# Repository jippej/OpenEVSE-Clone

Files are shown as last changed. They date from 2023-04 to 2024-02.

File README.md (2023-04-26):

# OpenEVSE-Clone

This is an hardware design which is based on OpenEVSE, compatible with the OpenEVSE firmware, and suited to my needs.
Key changes in respect to the original OpenEVSE boards (version 5.5):
- Removed DC relais control (I use a AC controlled relais)
- GFCI detection removed (I use an external ELCB)
- Removed AC/DC converter (I use an external DIN rail mounted 12VDC supply)
- form factor adjusted to be fitted in a standard DIN rail housing
- Added H-Bridge driver for "cable lock" mechanism
- Added mounting for ESP32 Gateway

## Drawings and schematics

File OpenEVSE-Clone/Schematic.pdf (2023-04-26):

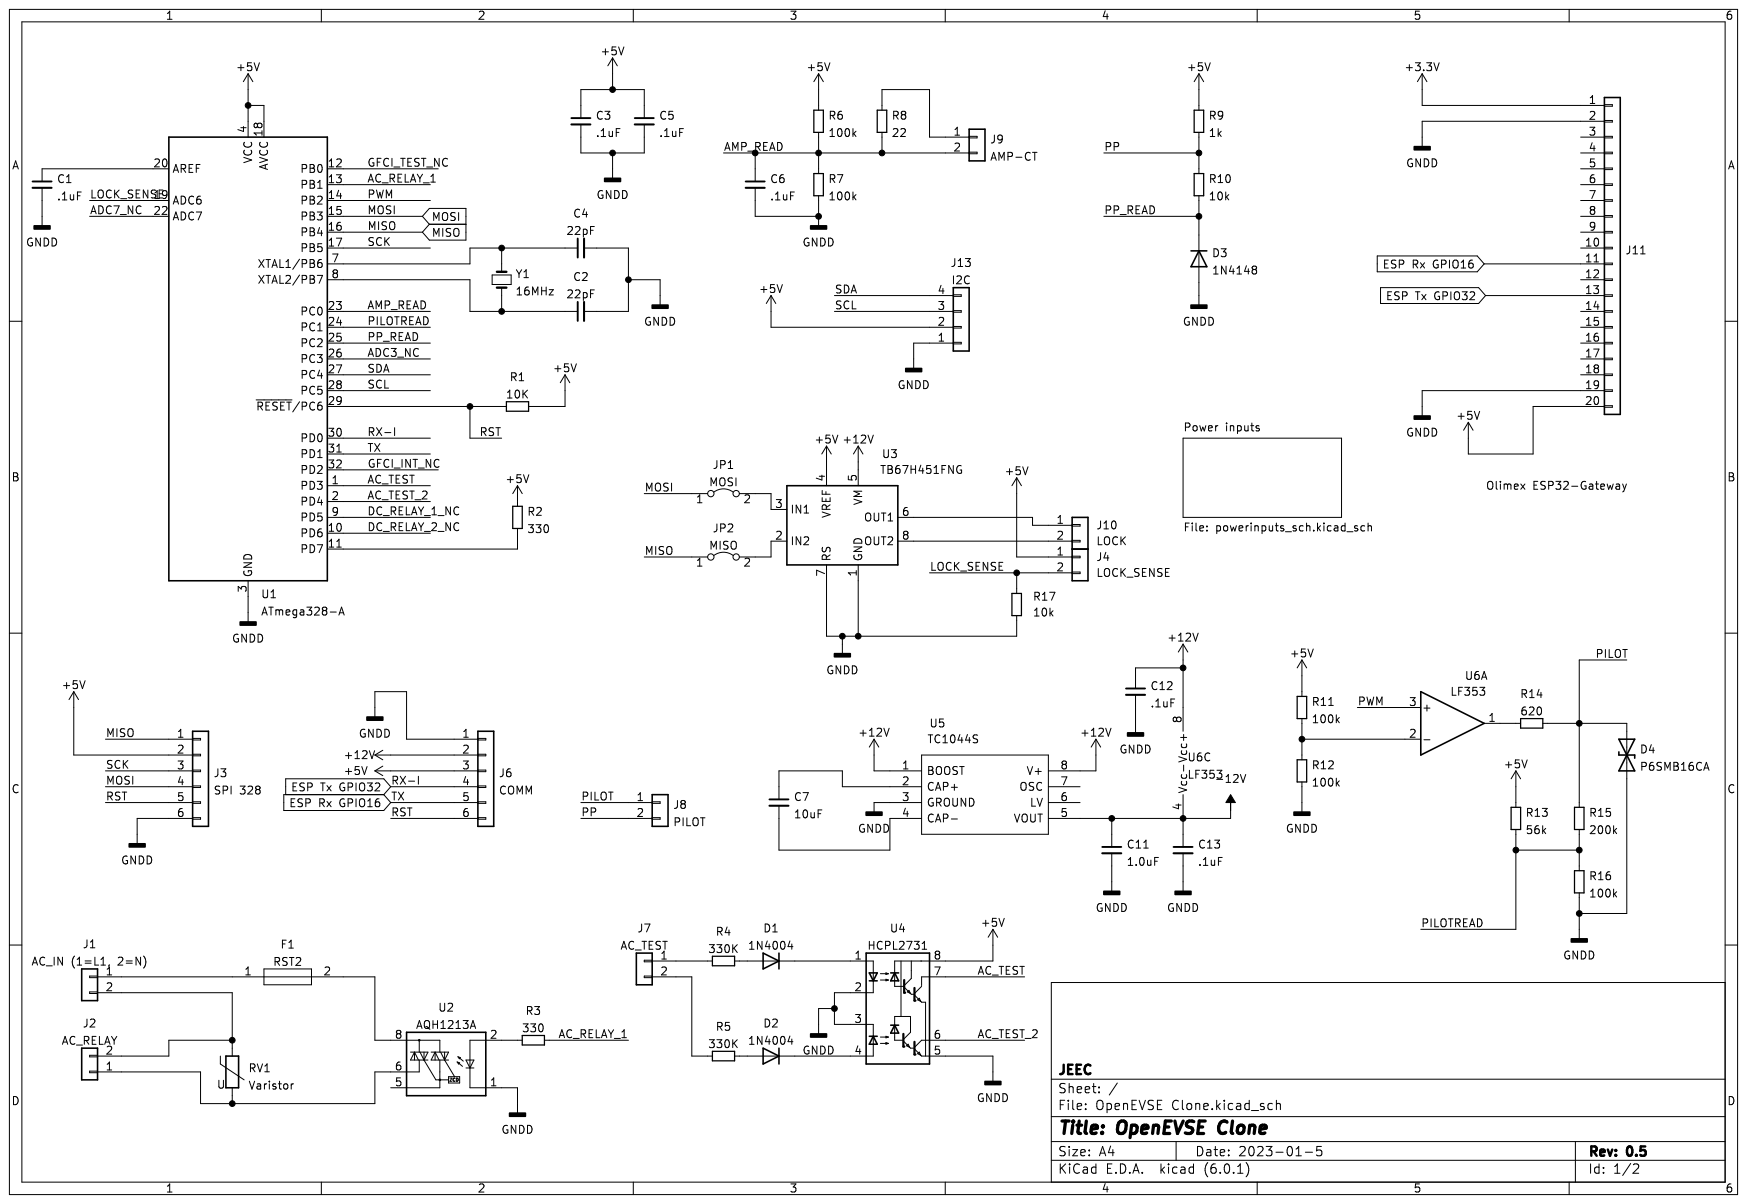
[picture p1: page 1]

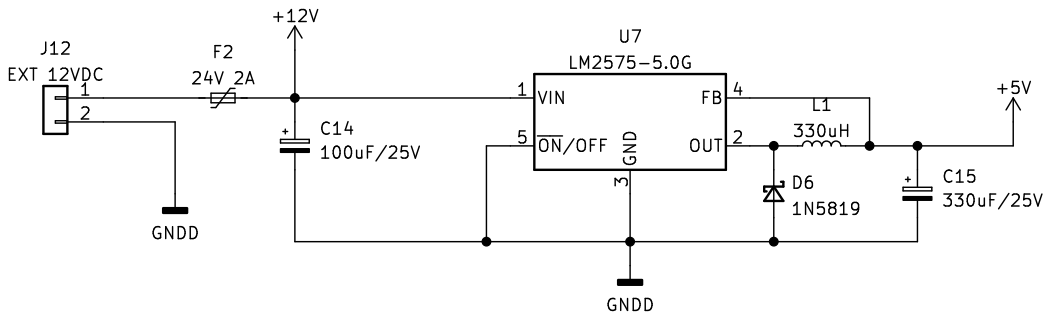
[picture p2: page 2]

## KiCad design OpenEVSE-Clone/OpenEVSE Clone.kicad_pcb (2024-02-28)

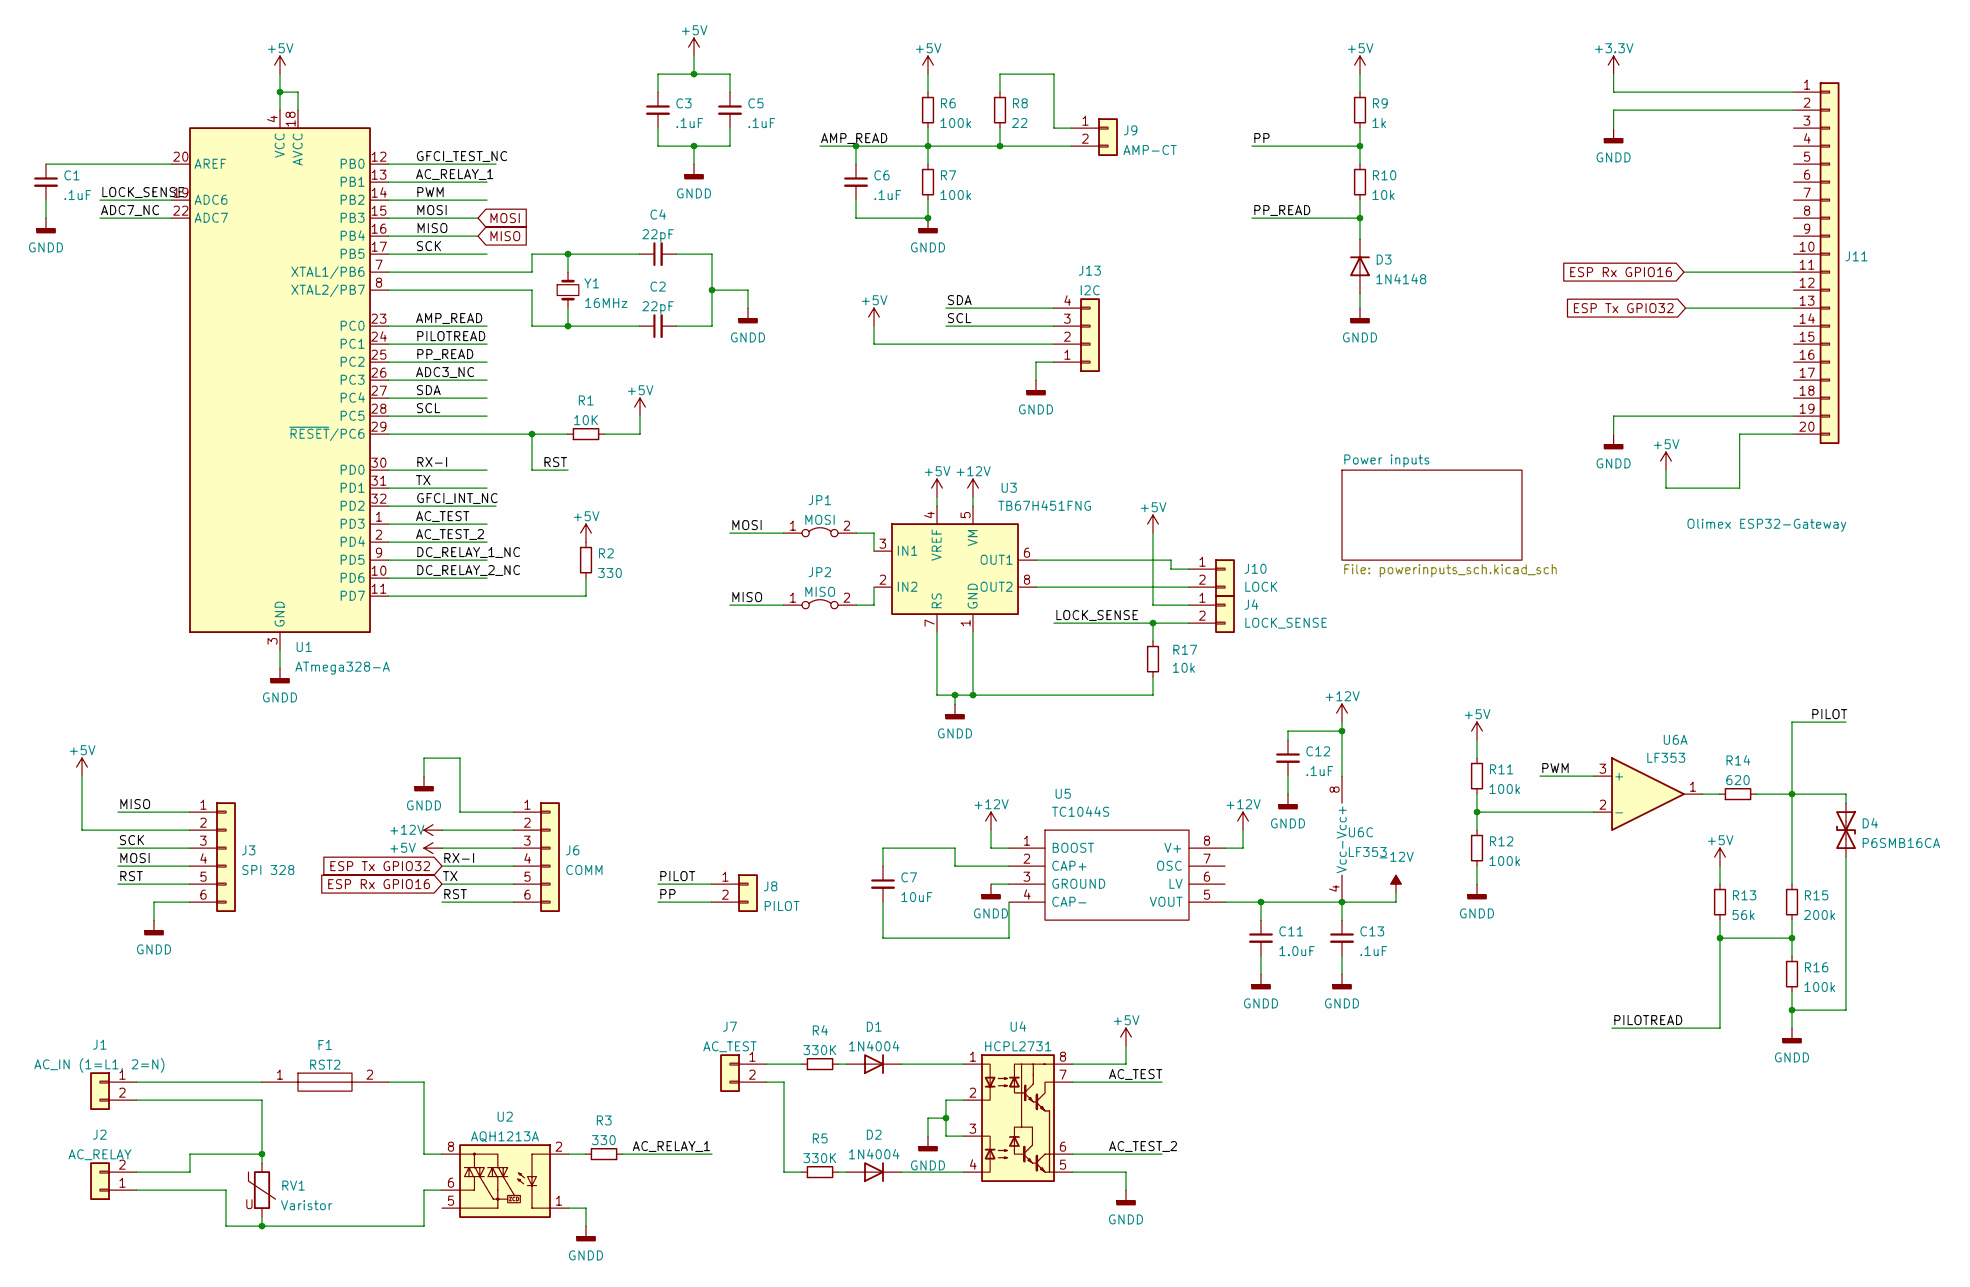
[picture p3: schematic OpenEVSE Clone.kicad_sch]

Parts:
C1, C3, C5, C6, C12, C13: .1uF; C_0805_2012Metric_Pad1.18x1.45mm_HandSolder
C2, C4: 22pF; C_0805_2012Metric_Pad1.18x1.45mm_HandSolder
C7: 10uF; C_0805_2012Metric_Pad1.18x1.45mm_HandSolder
C11: 1.0uF; C_0805_2012Metric_Pad1.18x1.45mm_HandSolder
D1, D2: 1N4004; D_SMA
D3: 1N4148; D_SOD-123
D4: P6SMB16CA; D_SMB
F1: RST2; RST2AMMO; Manufacturer_Part_Number RST 2 AMMO; Mouser Part Number 530-RST2AMMO
J1: AC_IN (1=L1, 2=N); TerminalBlock_Phoenix_MKDS-3-2-5.08_1x02_P5.08mm_Horizontal
J2: AC_RELAY; TerminalBlock_Phoenix_MKDS-3-2-5.08_1x02_P5.08mm_Horizontal
J3: SPI 328; PinHeader_2x03_P2.54mm_Vertical
J4: LOCK_SENSE; TerminalBlock_Phoenix_MKDS-3-2-5.08_1x02_P5.08mm_Horizontal
J6: COMM; PinHeader_2x03_P2.54mm_Vertical
J7: AC_TEST; TerminalBlock_Phoenix_MKDS-3-2-5.08_1x02_P5.08mm_Horizontal
J8: PILOT; TerminalBlock_Phoenix_MKDS-3-2-5.08_1x02_P5.08mm_Horizontal
J9: AMP-CT; TerminalBlock_Phoenix_MKDS-3-2-5.08_1x02_P5.08mm_Horizontal
J10: LOCK; TerminalBlock_Phoenix_MKDS-3-2-5.08_1x02_P5.08mm_Horizontal
J11: Olimex ESP32-Gateway; PinSocket_1x20_P2.54mm_Vertical
J13: I2C; PinHeader_1x04_P2.54mm_Vertical
JP1: MOSI; PinSocket_1x02_P2.54mm_Vertical
JP2: MISO; PinSocket_1x02_P2.54mm_Vertical
R1: 10K; R_0805_2012Metric_Pad1.20x1.40mm_HandSolder
R2, R3: 330; R_0805_2012Metric_Pad1.20x1.40mm_HandSolder
R4, R5: 330K; R_2512_6332Metric
R6, R7, R11, R12, R16: 100k; R_0805_2012Metric_Pad1.20x1.40mm_HandSolder
R8: 22; R_0805_2012Metric_Pad1.20x1.40mm_HandSolder
R9: 1k; R_0805_2012Metric_Pad1.20x1.40mm_HandSolder
R10, R17: 10k; R_0805_2012Metric_Pad1.20x1.40mm_HandSolder
R13: 56k; R_0805_2012Metric_Pad1.20x1.40mm_HandSolder
R14: 620; R_0805_2012Metric_Pad1.20x1.40mm_HandSolder
R15: 200k; R_0805_2012Metric_Pad1.20x1.40mm_HandSolder
RV1: Varistor; RV_Disc_D7mm_W4.5mm_P5mm
U1: ATmega328-A; TQFP-32_7x7mm_P0.8mm
U2: AQH1213A; SSO-7-8_6.4x9.78mm_P2.54mm
U3: TB67H451FNG; HSOP-8-1EP_3.9x4.9mm_P1.27mm_EP2.41x3.1mm_ThermalVias
U4: HCPL2731; SMDIP-8_W9.53mm
U5: TC1044S; SOIC-8_3.9x4.9mm_P1.27mm; Manufacturer_Part_Number LTC1044CN8#PBF; Mouser Part Number 584-LTC1044CN8#PBF
U6: LF353; SOIC-8_3.9x4.9mm_P1.27mm
Y1: 16MHz; Crystal_SMD_2016-4Pin_2.0x1.6mm

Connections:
+3.3V: J11.1
+5V: C3.1, C5.1, J3.2, J4.1, J6.3, J11.20, J13.2, R1.2, R2.1, R6.1, R9.1, R11.1, R13.1, U1.4 (VCC), U1.6 (VCC), U1.18 (AVCC), U3.4 (VREF), U4.8 (VCC); also elsewhere on the board
+12V: C12.1, J6.2, U3.5 (VM), U5.1 (BOOST), U5.8 (V+), U6.8 (Vcc+); also elsewhere on the board
-12V: C11.1, C13.1, U5.5 (VOUT), U6.4 (Vcc-)
/AC_RELAY_1: R3.1, U1.13 (PB1)
/AC_TEST: U1.1 (PD3), U4.7 (VO1)
/AC_TEST_2: U1.2 (PD4), U4.6 (VO2)
/ADC3_NC: U1.26 (PC3)
/ADC7_NC: U1.22 (ADC7)
/AMP_READ: C6.1, J9.2, R6.2, R7.1, R8.2, U1.23 (PC0)
/DC_RELAY_1_NC: U1.9 (PD5)
/DC_RELAY_2_NC: U1.10 (PD6)
/GFCI_INT_NC: U1.32 (PD2)
/GFCI_TEST_NC: U1.12 (PB0)
/LOCK_SENSE: J4.2, R17.1, U1.19 (ADC6)
/PILOT: D4.1 (A1), J8.1, R14.2, R15.1
/PILOTREAD: R13.2, R15.2, R16.1, U1.24 (PC1)
/PP: J8.2, R9.2, R10.1
/PP_READ: D3.1 (K), R10.2, U1.25 (PC2)
/PWM: U1.14 (PB2), U6.3 (+)
/RST: J3.5, J6.6, R1.1, U1.29 (~RESET/PC6)
/SCK: J3.3, U1.17 (PB5)
/SCL: J13.3, U1.28 (PC5)
/SDA: J13.4, U1.27 (PC4)
ESP Rx GPIO16: J6.5, J11.11, U1.31 (PD1)
ESP Tx GPIO32: J6.4, J11.13, U1.30 (PD0)
GNDD: C1.2, C2.2, C3.2, C4.2, C5.2, C6.2, C11.2, C12.2, C13.2, D3.2 (A), D4.2 (A2), J3.6, J6.1, J11.2, J11.19, J13.1, R7.2, R12.2, R16.2, R17.2, U1.3 (GND), U1.5 (GND), U1.21 (GND), U2.1, U2.3, U2.4, U3.1 (GND), U3.7 (RS), U3.9 (GND), U4.2 (C1), U4.3 (C2), U4.5 (GND), U5.3 (GROUND); also elsewhere on the board
MISO: J3.1, JP2.1 (A), U1.16 (PB4)
MOSI: J3.4, JP1.1 (A), U1.15 (PB3)
unnamed: C1.1, U1.20 (AREF)
unnamed: C2.1, U1.8 (XTAL2/PB7), Y1.2
unnamed: C4.1, U1.7 (XTAL1/PB6), Y1.1
unnamed: C7.1, U5.2 (CAP+)
unnamed: C7.2, U5.4 (CAP-)
unnamed: D1.1 (K), U4.1 (A1)
unnamed: D1.2 (A), R4.2
unnamed: D2.1 (K), U4.4 (A2)
unnamed: D2.2 (A), R5.2
unnamed: F1.1, J1.1
unnamed: F1.2, U2.8
unnamed: J1.2, J2.2, RV1.1
unnamed: J2.1, RV1.2, U2.6
unnamed: J7.1, R4.1
unnamed: J7.2, R5.1
unnamed: J9.1, R8.1
unnamed: J10.1, U3.6 (OUT1)
unnamed: J10.2, U3.8 (OUT2)
unnamed: JP1.2 (B), U3.3 (IN1)
unnamed: JP2.2 (B), U3.2 (IN2)
unnamed: R2.2, U1.11 (PD7)
unnamed: R3.2, U2.2
unnamed: R11.2, R12.1, U6.2 (-)
unnamed: R14.1, U6.1

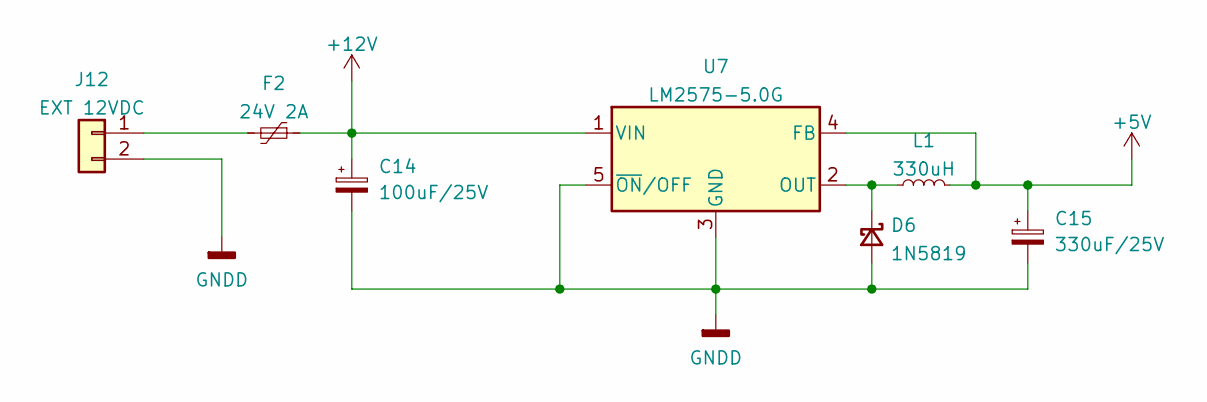
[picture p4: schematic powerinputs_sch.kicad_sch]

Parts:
C14: 100uF/25V; CP_Radial_D6.3mm_P2.50mm
C15: 330uF/25V; CP_Radial_D10.0mm_P5.00mm
D6: 1N5819; D_SOD-123
F2: 24V 2A; Fuse_2920_7451Metric_Pad2.10x5.45mm_HandSolder
J12: EXT 12VDC; TerminalBlock_Phoenix_MKDS-3-2-5.08_1x02_P5.08mm_Horizontal
L1: 330uH; L_Radial_D8.7mm_P5.00mm_Fastron_07HCP
U7: LM2575-5.0G; TO-263-5_TabPin3

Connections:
+5V: C15.1, L1.2, U7.4 (FB); also elsewhere on the board
+12V: C14.1, F2.1, U7.1 (VIN); also elsewhere on the board
GNDD: C14.2, C15.2, D6.2 (A), J12.2, U7.3 (GND), U7.5 (~ON/OFF); also elsewhere on the board
unnamed: D6.1 (K), L1.1, U7.2 (OUT)
unnamed: F2.2, J12.1

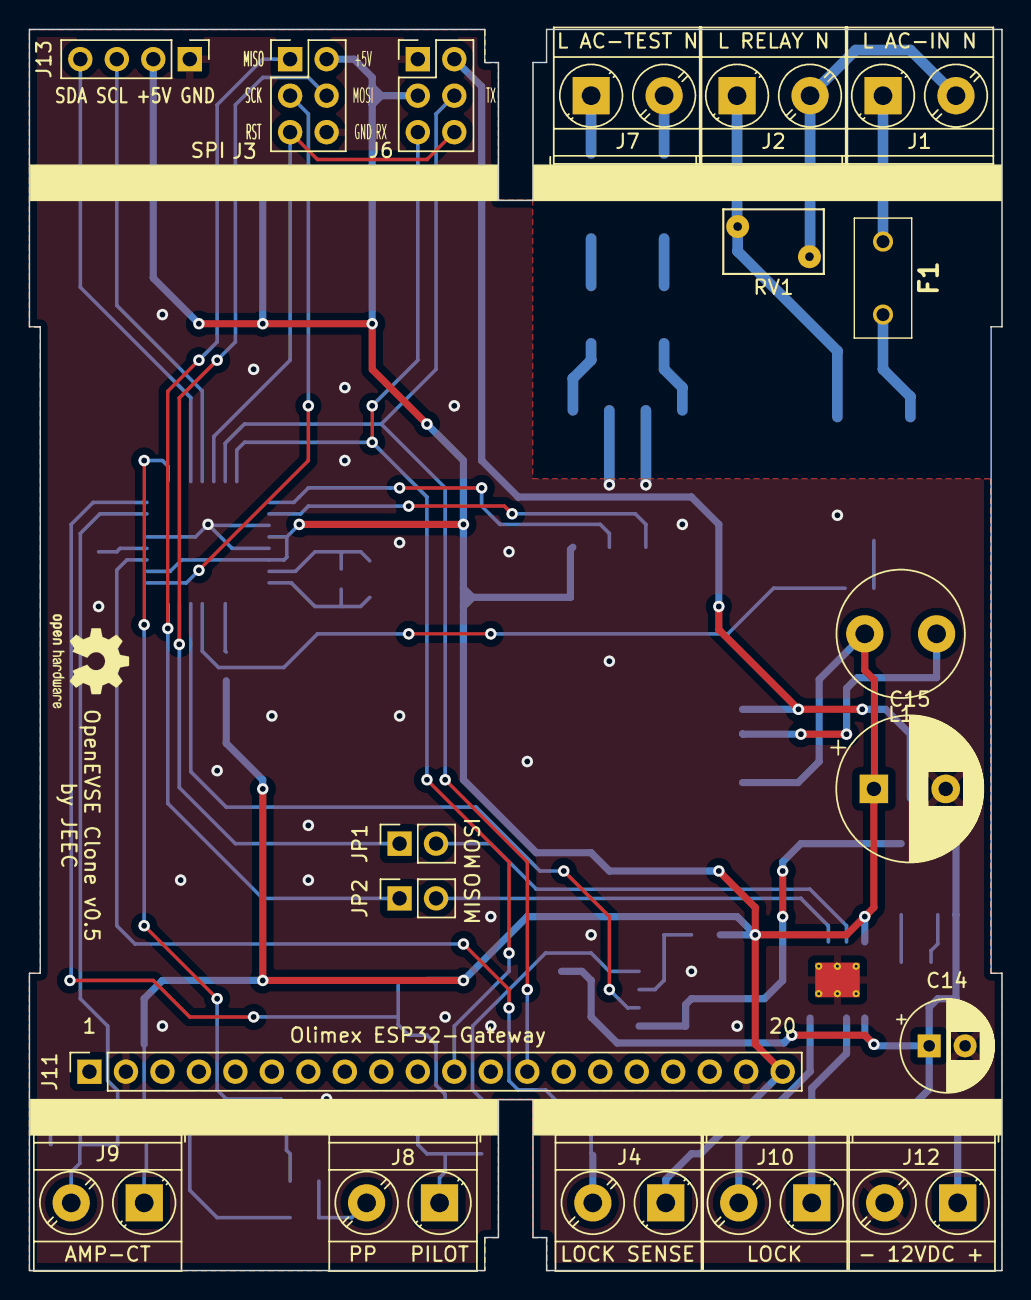
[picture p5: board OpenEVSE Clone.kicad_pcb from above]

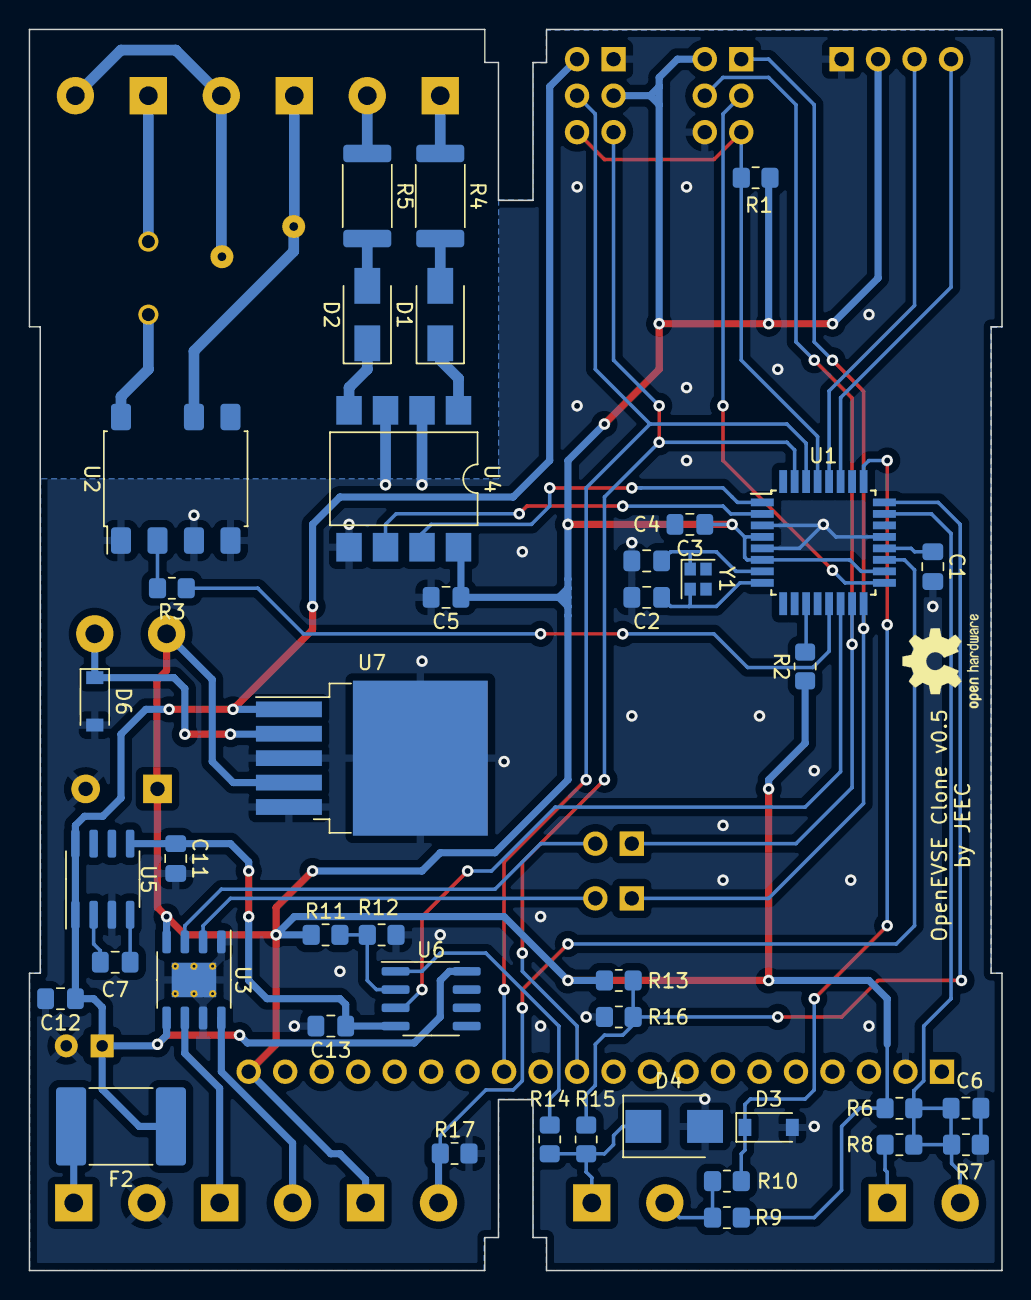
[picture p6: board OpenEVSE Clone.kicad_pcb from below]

Board: 2 copper layers, 67.7 x 86.4 mm, 60 parts (41 on the bottom side), 48 nets.

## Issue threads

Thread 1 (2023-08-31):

Missing external Earth connection

jippej, 2023-08-31:
Seperate earth connection to be added.
work around:
GND 12V connection also earth connected

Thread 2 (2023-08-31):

External CT not working

jippej, 2023-08-31:
External CT is not working due to mistake in current sense circuit

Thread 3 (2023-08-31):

Mennekes Lock not working

jippej, 2023-08-31:
Locking mechanism is not working with implemented H-bridge driver

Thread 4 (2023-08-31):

Addition of temperature sensor MCP9808

jippej, 2023-08-31:
Suggest to include a temperature sensor on the board in a proper location.
Add jumpers to be able to disconnect the temp sensor if an openevse LCD is connected

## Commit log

2023-04-26 Schematics and PCB layout added
    [OpenEVSE Clone.kicad_pcb, OpenEVSE Clone.kicad_sch, powerinputs_sch.kicad_sch]
2024-02-28 Changed folder name
    [OpenEVSE Clone.kicad_pcb, OpenEVSE Clone.kicad_sch, powerinputs_sch.kicad_sch]
